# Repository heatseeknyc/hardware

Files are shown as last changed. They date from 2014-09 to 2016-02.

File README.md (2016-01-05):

## Heat Seek NYC Hardware

### Overview

connect XBee to the π via serial GPIO pins

listen for IO frames, which are of the form 0x7E....92

use a (manually maintained) mapping of 64-bit sensor addresses to apartments, to record apartment temperatures

### XBee-DigiMesh

Unlike XBee Zigbee, it supports synchronized sleeping, for low-power meshing.

The [chip](http://www.digikey.com/product-detail/en/XB24-DMPIT-250/602-1338-ND/3482610) — this is the same hardware as [XBee Series 1](http://www.digikey.com/product-detail/en/XB24-API-001/602-1273-ND/3482588) but with DigiMesh firmware pre-installed.

The [docs](http://ftp1.digi.com/support/documentation/90000991_L.pdf).

Adding a new node is slightly trickier, but if the π node is in "Synchronous Sleep Support Mode" SM=7, then you can just bring a new node near the π at any time and it will sync up with the rest of the sleeping (SM=8) nodes.

### Alternatives

#### XBee-Zigbee

Can't both sleep and mesh, but has a better ADC, perhaps among other things.

Make sure to connect VREF to VCC. This is basically undocumented, but without it the chip basically crashes after a minute of reading from the ADC. _TODO_ email Digi about this.

The [chip](http://www.digikey.com/product-detail/en/XB24-Z7PIT-004/602-1275-ND/3482624), aka XBee Series 2.

The [docs](http://ftp1.digi.com/support/documentation/90000976_S.pdf)

### GERBER Files
If you need to generate a GERBER file, follow the instructions in [this tutorial](https://learn.sparkfun.com/tutorials/using-eagle-board-layout/generating-gerbers). You just clone [their repo](https://github.com/sparkfun/SparkFun_Eagle_Settings) and use `sfe-gerb274x.cam`.

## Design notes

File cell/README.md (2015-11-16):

# Cell node

## Electrical

### Components

See the [spreadsheet](https://docs.google.com/spreadsheets/d/1aLX0yPriqRYv9exc7hV8ZaoWDZZKsPV997NUnLpyvPM/edit?usp=sharing).

#### Searching for capacitors
for now we're using Kemet X7R 50V ±10% ceramic 0805s and through-hole radial capacitors

so to search go [here](http://www.digikey.com/product-search/en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) and then filter by capacitance

#### Temperature Sensor Chips
- our current chip: [surface mount analog temperature sensor](http://www.digikey.com/product-detail/en/MCP9700AT-E%2FTT/MCP9700AT-E%2FTTCT-ND/3622388) ±2°C from 0°C to 70°C, $0.24
- [surface mount RTD](http://www.digikey.com/product-detail/en/PTS080501B500RP100/PTS0805500CT-ND/1666191) ±0.5°C from -40°C to 40°C, $1.91
- [surface mount analog temperature sensor](http://www.digikey.com/product-detail/en/DS600U%2B/DS600U%2B-ND/1197625), ±0.5°C from -20°C to 100°C, $2.58
- [ball grid array analog temperature sensor](http://www.digikey.com/product-detail/en/LMT70YFQT/296-42088-1-ND/5252841) ±0.2°C from -20°C to 90°C, $1.73

### Power consumption

The input range of the MCP1700 is about 3.5V to absolute maximum 6.5V,
so we use 4xAAA batteries, which gives us an initial voltage of about 6.4V, and a voltage of about 4V after 1000mAh.

- MCP1700 quiescent current < 4µA
- XBee cyclic sleep current < 50µA
- Xbee transmit current < 45mA / 250mA PRO
- XBee idle/receive current < 50mA / 55mA PRO
- XBee ADC current **??**
- MCP9700 operating current < 12µA

**TODO** measure these!
- total sleeping current < 54µA
- total waking current < 50mA / 250mA PRO

#### Setup mode

If we transmit constantly, we use 50mA / 250mA PRO, so every hour of setup we use 1.3% / 6.3% PRO of the batteries.

#### Live mode

So if we transmit for 5 seconds every hour, we use 124µAh / 402µAh PRO per hour, so 4x1000mAh battery would last 3.6 / 1.1 PRO years.

And if we transmit for 10 seconds every hour, we use 193µAh / 749µAh PRO per hour, so 4x1000mAh battery would last 2.3 / 0.6 PRO years.

## Mechanical

### flat battery holder mounting

assuming symmetry, mounting hole centers are offset from left and right edges by (1.98" - 0.5") / 2 = 0.74"

terminals are offset from bottom by 0.102"

### XBee dimensions, including *full height* of [socket](http://www.sullinscorp.com/drawings/75_1BFC_10483.pdf)

XBee is smaller than XBee-PRO, `32.94mm - 5.33mm = 27.61mm`

    24.38mm W x 27.61mm D x 9.79mm (2.79mm + 7.0mm) H

### battery holder dimensions

[3d model](flat-case-squat-case-and-us-quarter.stl) of flat and squat cases and a quarter

#### [flat](http://www.digikey.com/product-detail/en/2481/2481K-ND/303826)

    50.79mm W x 54.51mm D x 23.29mm (13.5mm + 9.79mm) H
    2.00" W x 2.15" D x 0.92" H

#### [squat](http://www.digikey.com/product-detail/en/BH24AAAW/BH24AAAW-ND/38633)

    26mm W x 53mm D x 35mm (25mm + 10mm) H

### cases

#### [TS-3315P](http://www.polycase.com/ts-3315p)

    3.00" x 3.00" x 1.50", weight=2.1oz, volume=13.5""", price=$2.05

#### [LP-41P](http://www.polycase.com/lp-41p)

    3.29" x 3.29" x 1.25", weight=3.2oz, volume=13.53""", price=$2.66

#### [CU-791](http://www.budind.com/view/Plastic+Boxes/Utilibox+Style+E)

    3.08" x 3.08" x 1.50", weight=1.5oz, volume=14.23""", price=$2.86

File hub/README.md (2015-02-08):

# Hub node

## Serial connection

- GPIO pin 1 (3v3) to XBee pin 1 (VCC)
- GPIO pin 6 (GND) to XBee pin 10 (GND)
- GPIO pin 8 (TXD) to XBee pin 3 (DIN)
- GPIO pin 10 (RXD) to XBee pin 2 (DOUT)

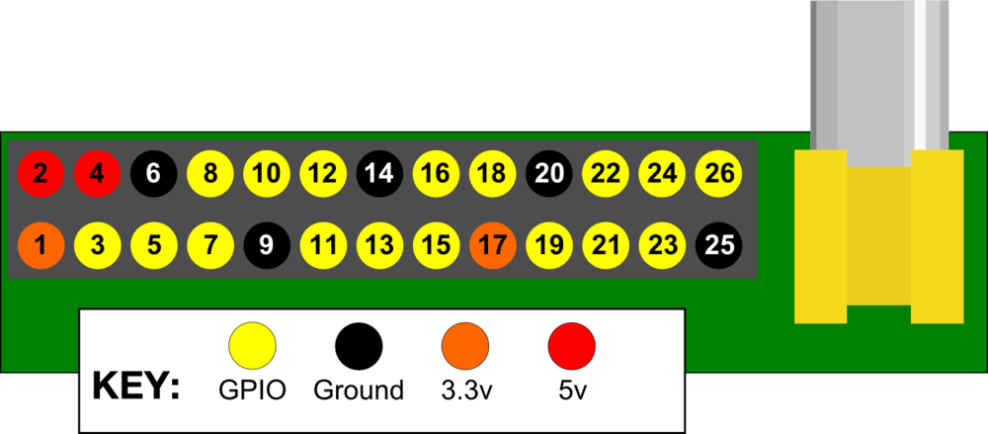
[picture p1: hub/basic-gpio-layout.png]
GPIO pin layout


## Data usage

Assuming each reading is ~100 bytes (the reading itself may be as little as 20-30 bytes, plus the HTTP headers), and each cell takes 24 readings per day, that's 24 x 100 = 2,400 bytes per day per cell, or 2.4 kilobytes (roughly, 1kb = 1024b).

Assuming a base is connected to 10 cells, then the base will be transmitting 10 x 2.4 = 24 kilobytes per day.
Assuming 31 days per month (worst case), and 365 days per year, data usage will be:

|numCells|Data/Day|Data/Month|Data/120d|Data/Year|
|---|---|---|---|---|
|1 |2.4 kb  |0.0744 mb |0.288 mb |0.876 mb |
|10 |24 kb |0.744 mb  |2.88 mb  |8.76 mb  |
|15 |36 kb |1.17 mb |4.32 mb  |13.14 mb |
|20 |48 kb |1.48 mb |5.76 mb  |17.52 mb |
|30 |72 kb |2.23 mb |8.64 mb  |26.28 mb |
|50 |120 kb  |3.72 mb |14.4 mb  |43.8 mb  |
|100 |240 kb  |7.44 mb |28.8 mb  |87.6 mb  |

Pre-paid Vodafone SIM cards:
- [1MB/month for a year](http://www.embeddedworks.net/wsim2730.html) for $31.27, or $2.61/MB
- [5MB/month for 6 months](http://www.embeddedworks.net/wsim2737.html) for $46.11, or $1.54/MB
- [10MB/month for a year](http://www.embeddedworks.net/wsim2786.html) for $137.41, or $1.15/MB

## 3G modems

There's a [generic stick](http://www.amazon.com/Generic-Wireless-7-2Mbps-Dongle-Function/dp/B00MHAKIJY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) for ~$13 and a [branded alternative](http://www.amazon.com/Huawei-E173-Unlocked-HSDPA-7-2Mbps/dp/B0055310KQ) for ~$26. Given that we currently budget $6 for a USB WiFi dongle, each of these represents some increase to the cost of the base, $7 and $20, respectively.

[Verified 3G USB dongles](http://elinux.org/RPi_VerifiedPeripherals#USB_3G_Dongles)

## Alternatives

connect the HSDPA (3G) dongle to an [Arduino USB Host Shield](https://www.sparkfun.com/products/9947), to see how easy direct USB 3G modem AT commands are... possibly not easy.

connect a [FONA GSM (2G) board](https://www.adafruit.com/fona) to an Arduino or whatever. this isn't cheaper than a Raspberry Pi, but could lead to a cheaper PCB.

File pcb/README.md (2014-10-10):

#### XBee dimensions, including [socket](http://www.sullinscorp.com/drawings/75_1BFC_10483.pdf)

25mm W x 28mm L x 10mm (3mm + 7mm) D

#### battery holder dimensions

https://github.com/heatseeknyc/hardware/blob/master/pcb/flat-case-squat-case-and-us-quarter.stl

##### [flat](http://www.digikey.com/product-detail/en/2481/2481K-ND/303826)

51mm W x 54mm L x 23mm (13mm + 10mm) D (assuming PC pins are clipped)

##### [squat](http://www.digikey.com/product-detail/en/BH24AAAW/BH24AAAW-ND/38633)

26mm W x 53mm L x 35mm (25mm + 10mm) D

#### flat battery holder mounting

assuming symmetry, mounting hole centers are offset from left and right edges by (1.98" - 0.5") / 2 = 0.74"

terminals are offset from bottom by 0.102"

#### searching for capacitors

for now we're using Kemet X7R 50V ±10% ceramic 0805s and through-hole radial capacitors

so to search go [here](http://www.digikey.com/product-search/en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) and then filter by capacitance

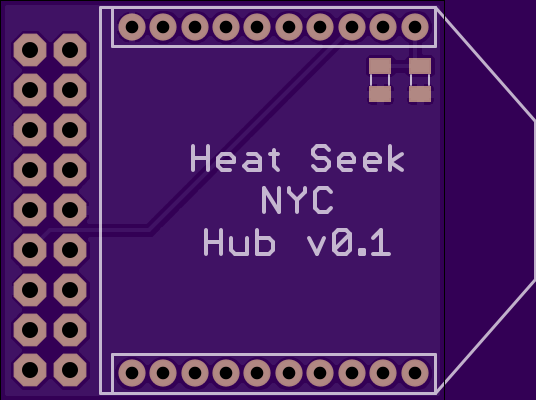
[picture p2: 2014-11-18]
hub/without/v0.1.png

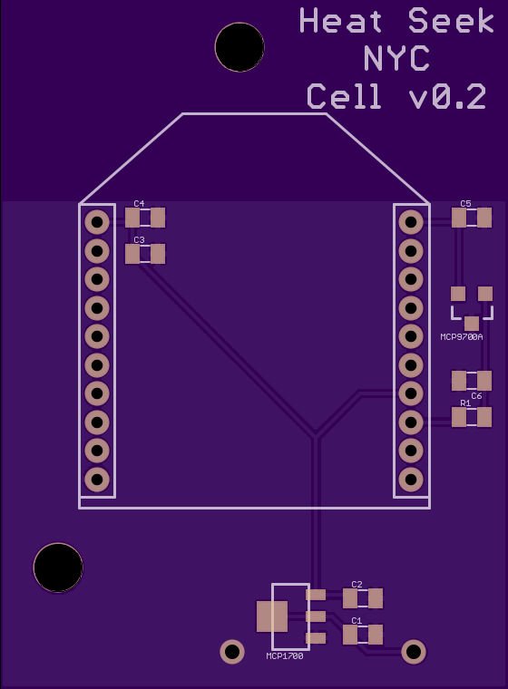
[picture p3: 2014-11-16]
cell/v0.2.png

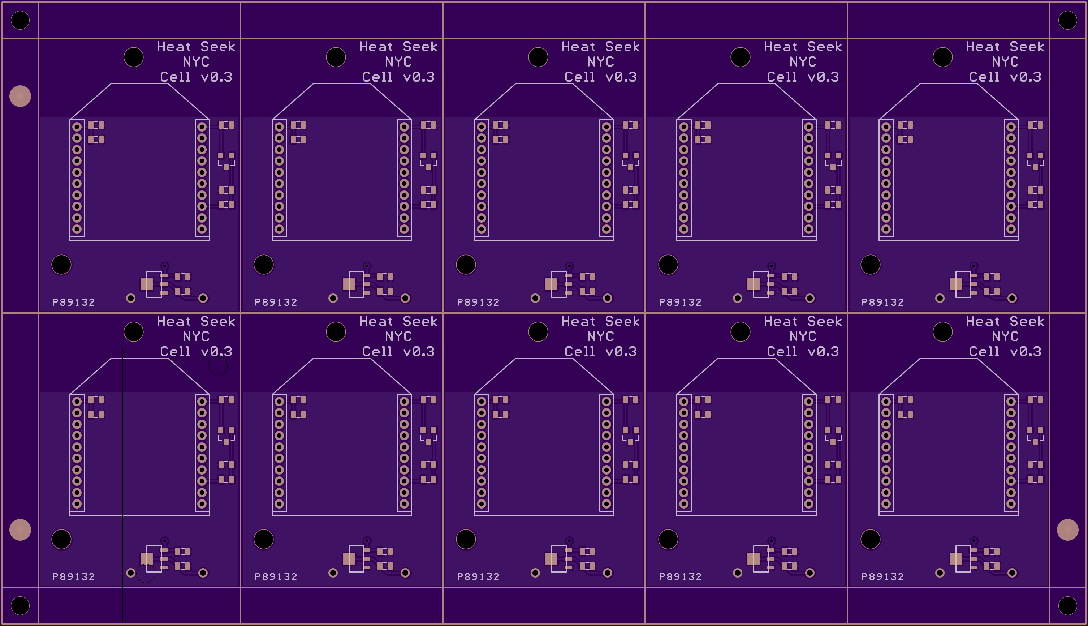
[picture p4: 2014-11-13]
cell/v0.3-array.png

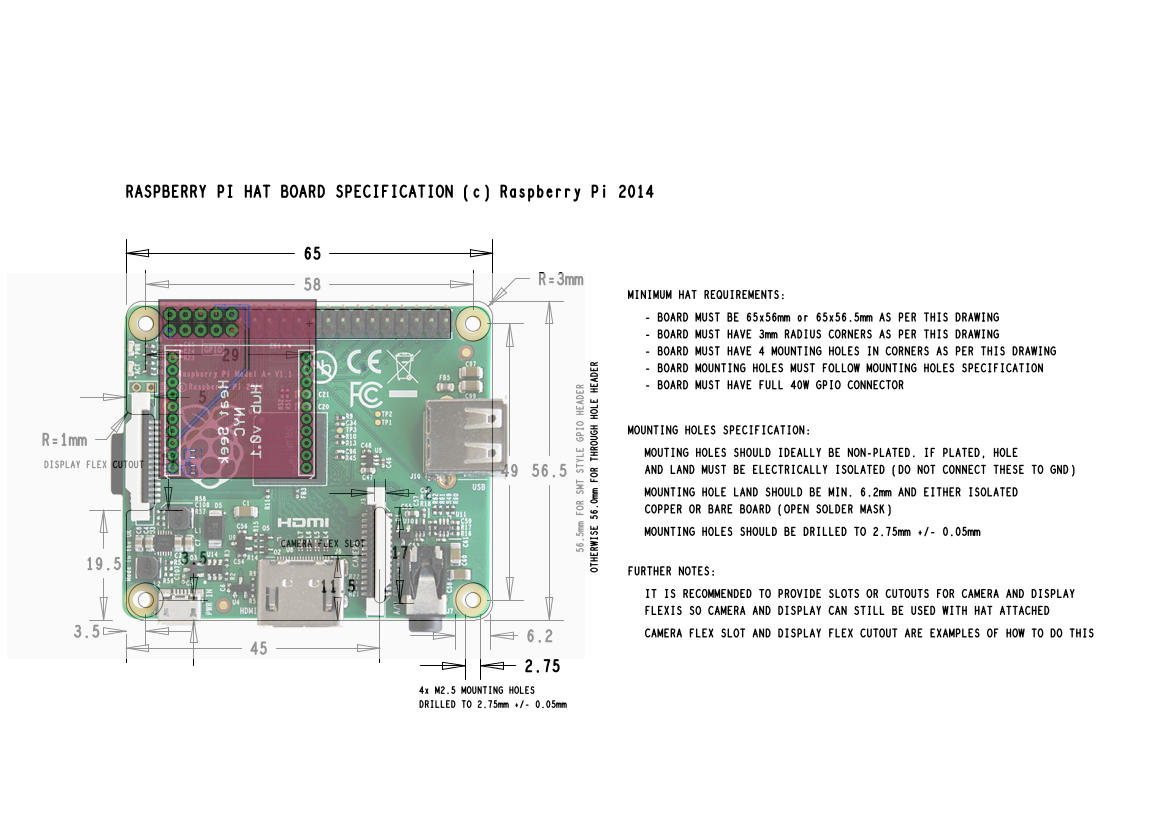
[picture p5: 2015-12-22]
hub/stacked/v0.1-within.png

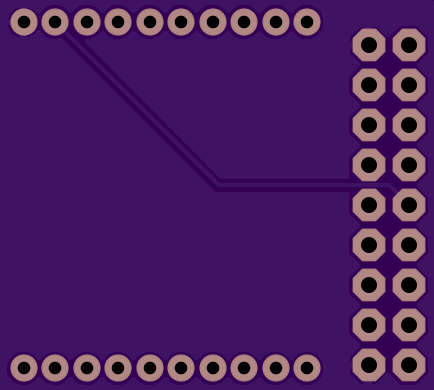
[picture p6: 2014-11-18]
hub/v0.1-bottom.png

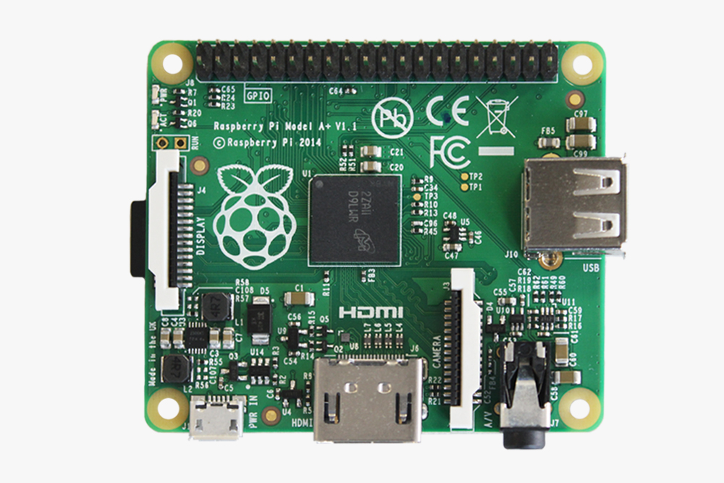
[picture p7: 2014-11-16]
hub/stacked/π-a+.jpg

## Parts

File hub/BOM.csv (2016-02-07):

Description | QTY | Ref Des | Mfg P/N # | Distributor | Distributor P/N #
CAP CER 1UF 50V 10% X7R 0805 | 1 | C1 | C0805C105K5RACTU | Digi-Key | 399-7409-1-ND
CAP CER 8.2PF 50V NP0 0805 | 1 | C2 | C0805C829D5GACTU | Digi-Key | 399-8121-1-ND
CONN FMALE 18POS DL .1" GOLD SMD | 1 | Rπ | NPPC092KFMS-RC | Digi-Key | S5718-ND
CONN RECEPT 2MM SINGLE STR 10POS | 2 | XB1, XB2 | NPPN101BFLC-RC | Digi-Key | S5901-10-ND

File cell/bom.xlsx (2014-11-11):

Description | QTY | Ref Des | Mfg P/N # | Distributor | Distributor P/N #
HOLDER BATTERY 4CELL AAA PC MNT (http://www.digikey.com/product-detail/en/2481/2481K-ND/303826) | 1 |  | 2481 | Digi-Key | 2481K-ND
CONN RECEPT 2MM SINGLE STR 10POS (http://www.digikey.com/product-detail/en/NPPN101BFCN-RC/S5751-10-ND/804812) | 2 |  | NPPN101BFCN-RC | Digi-Key | S5751-10-ND
IC REG LDO 3.3V 0.25A SOT89-3 (http://www.digikey.com/product-detail/en/MCP1700T-3302E%252FMB/MCP1700T3302EMBCT-ND/652679) | 1 | MCP1700 | MCP1700T-3302E/MB | Digi-Key | MCP1700T3302EMBCT-ND
IC SENSOR THERMAL 2.3V SOT-23-3 (http://www.digikey.com/product-detail/en/MCP9700AT-E%252FTT/MCP9700AT-E%252FTTCT-ND/3622388) | 1 | MCP9700A | MCP9700AT-E/TT | Digi-Key | MCP9700AT-E/TTCT-ND
CAP CER 1UF 50V 10% X7R 0805 (http://www.digikey.com/product-detail/en/C0805C105K5RACTU/399-7409-1-ND/3317443) | 4 | C1, C2, C3, C6 | C0805C105K5RACTU | Digi-Key | 399-7409-1-ND
CAP CER 8.2PF 50V NP0 0805 (http://www.digikey.com/product-detail/en/C0805C829D5GACTU/399-8121-1-ND/3471844) | 1 | C4 | C0805C829D5GACTU | Digi-Key | 399-8121-1-ND
CAP CER 0.1UF 50V 10% X7R 0805 (http://www.digikey.com/product-detail/en/C0805C104K5RACTU/399-1170-1-ND/411445) | 1 | C5 | C0805C104K5RACTU | Digi-Key | 399-1170-1-ND
RES 200 OHM 1/8W 1% 0805 (http://www.digikey.com/product-detail/en/RC2012F201CS/1276-5234-1-ND/3968206) | 1 | R1 | RC2012F201CS | Digi-Key | 1276-5234-1-ND

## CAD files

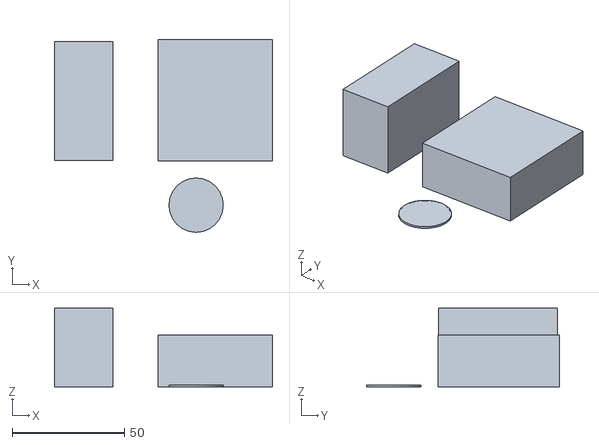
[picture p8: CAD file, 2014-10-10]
cell/flat-case-squat-case-and-us-quarter.stl
97.1 x 85.9 x 35.0

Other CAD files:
cell/cases.skp

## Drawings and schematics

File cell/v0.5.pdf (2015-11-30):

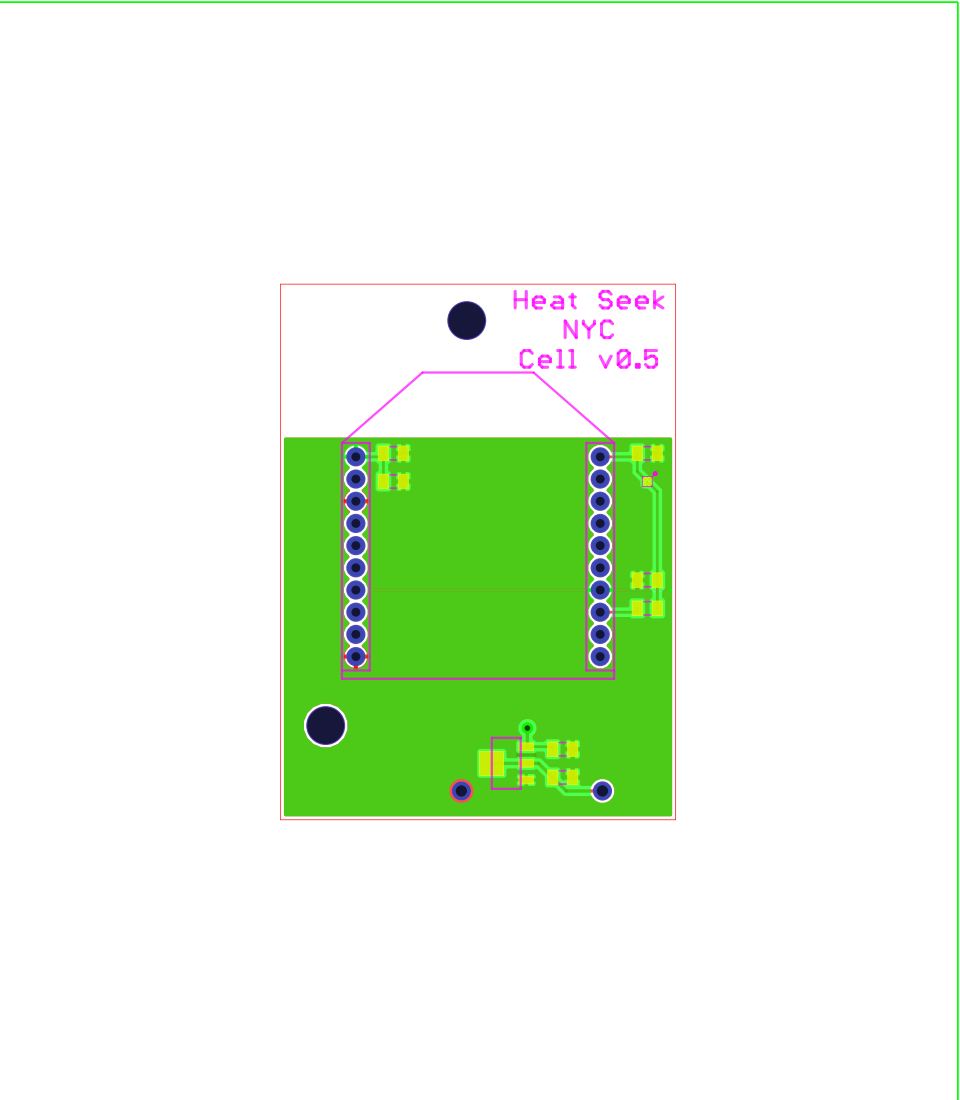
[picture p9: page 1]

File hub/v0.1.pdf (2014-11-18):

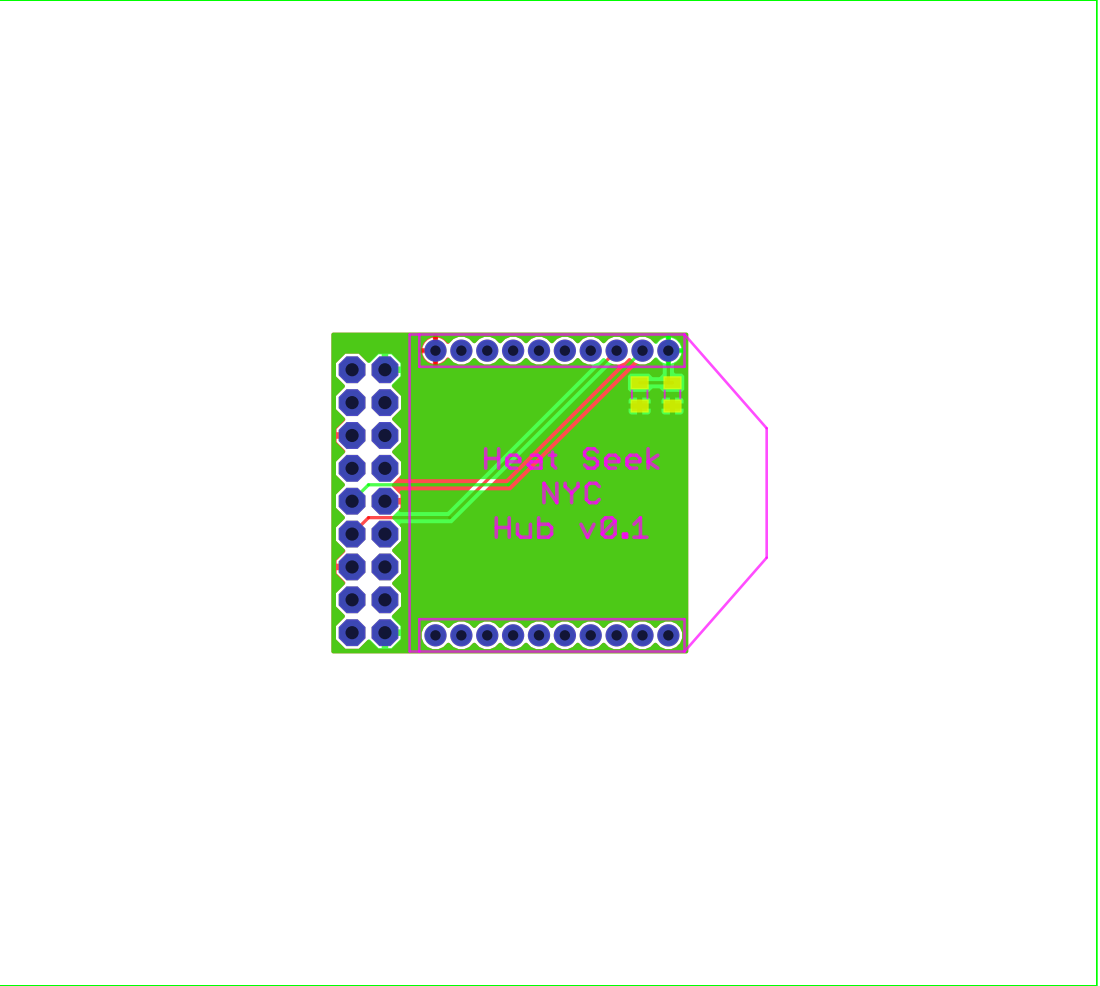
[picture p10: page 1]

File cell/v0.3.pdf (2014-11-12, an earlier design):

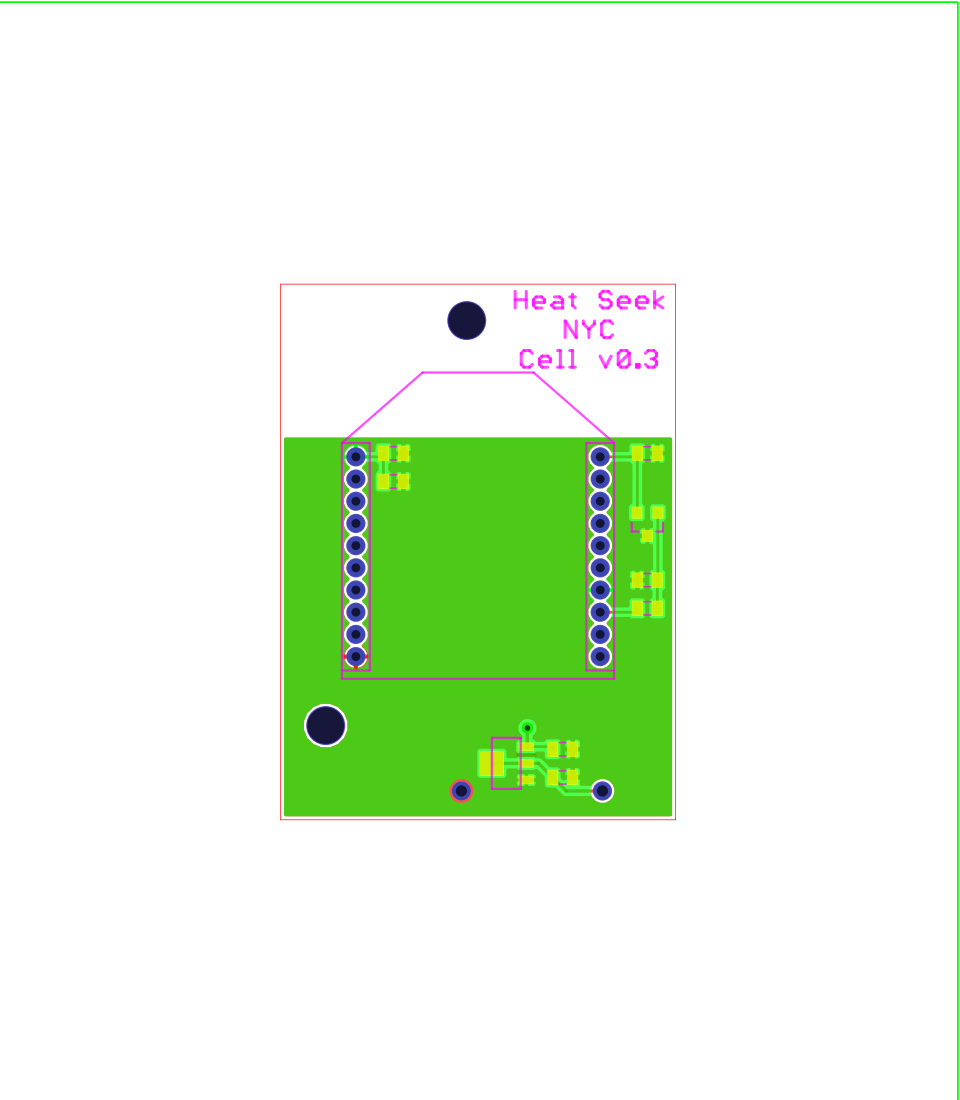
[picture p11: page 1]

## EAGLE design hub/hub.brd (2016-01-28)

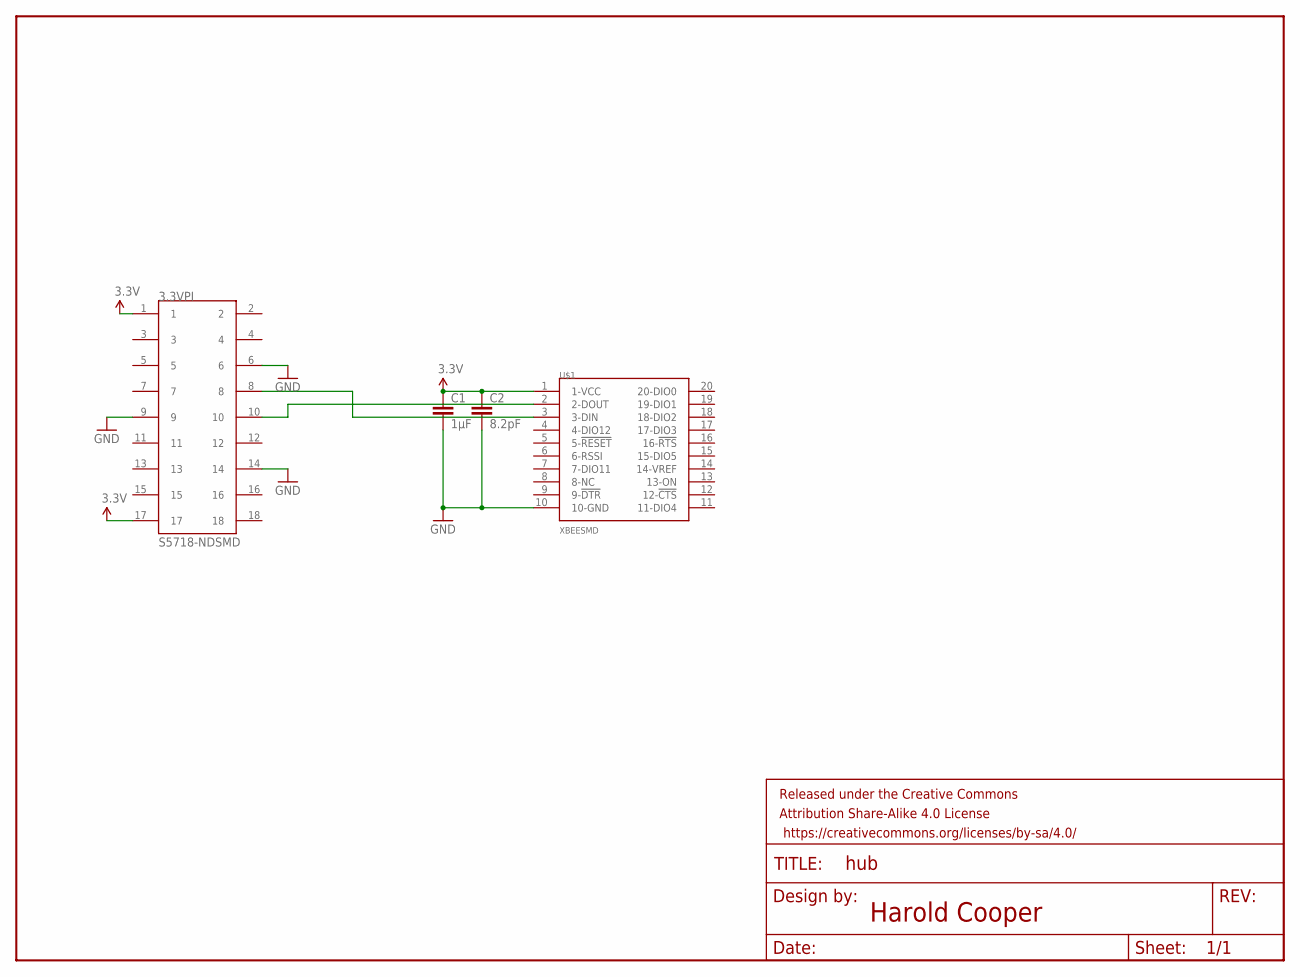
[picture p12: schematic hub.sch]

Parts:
3.3VPI: S5718-NDSMD; CONN_HEADER_SMD_18
C1: 1µF; 0805
C2: 8.2pF; 0805
FRAME1: FRAME-LETTER; CREATIVE_COMMONS
U$1: XBEESMD; CONN_HEADER_SMD_10X2

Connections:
3.3V: 3.3VPI.1, 3.3VPI.17, C1.1, C2.1, U$1.1 (1-VCC)
GND: 3.3VPI.6, 3.3VPI.9, 3.3VPI.14, C1.2, C2.2, U$1.10 (10-GND)
unnamed: 3.3VPI.10, U$1.2 (2-DOUT)
unnamed: 3.3VPI.8, U$1.3 (3-DIN)

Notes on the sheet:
Harold Cooper

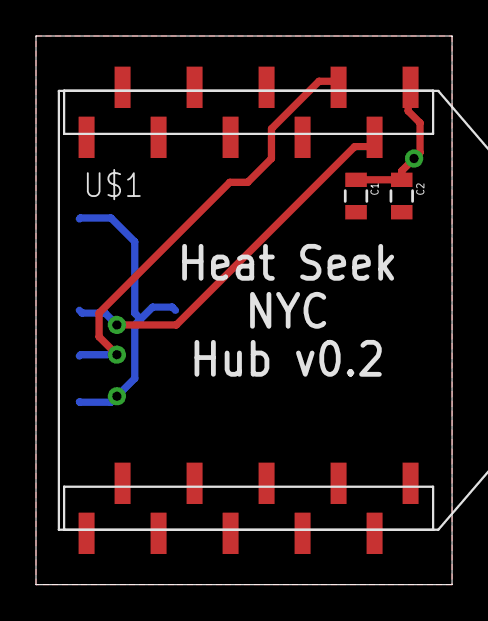
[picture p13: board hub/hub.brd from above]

Board: 2 copper layers, 23.1 x 30.5 mm, 5 parts (0 on the bottom side), 4 nets.

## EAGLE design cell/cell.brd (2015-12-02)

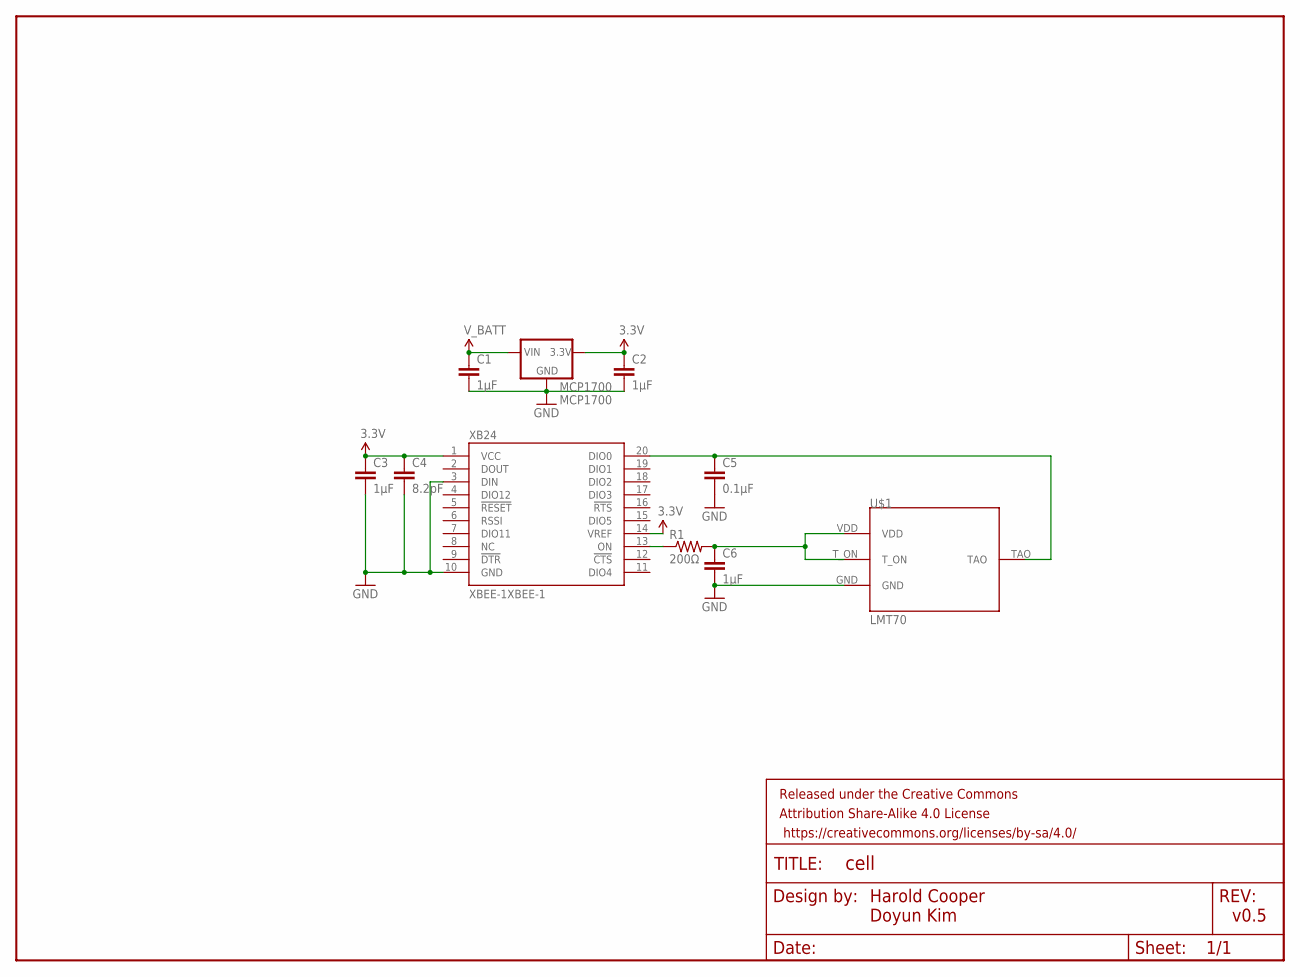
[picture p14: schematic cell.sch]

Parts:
C1, C2, C3, C6: 1µF; 0805
C4: 8.2pF; 0805
C5: 0.1µF; 0805
FRAME1: FRAME-LETTER; CREATIVE_COMMONS
MCP1700: MCP1700; SOT-89-3
R1: 200Ω; 0805
U$1: LMT70; YFP0004
XB24: XBEE-1XBEE-1; XBEE-1

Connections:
3.3V: C2.1, C3.1, C4.1, MCP1700.3 (3.3V), XB24.1 (VCC), XB24.14 (VREF)
GND: C1.2, C2.2, C3.2, C4.2, C5.2, C6.2, MCP1700.1 (GND), U$1.GND, XB24.3 (DIN), XB24.10 (GND)
unnamed: C6.1, R1.2, U$1.T_ON, U$1.VDD
unnamed: R1.1, XB24.13 (ON)
unnamed: C5.1, U$1.TAO, XB24.20 (DIO0)
V_BATT: C1.1, MCP1700.2 (IN)

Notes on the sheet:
Harold Cooper Doyun Kim
v0.5

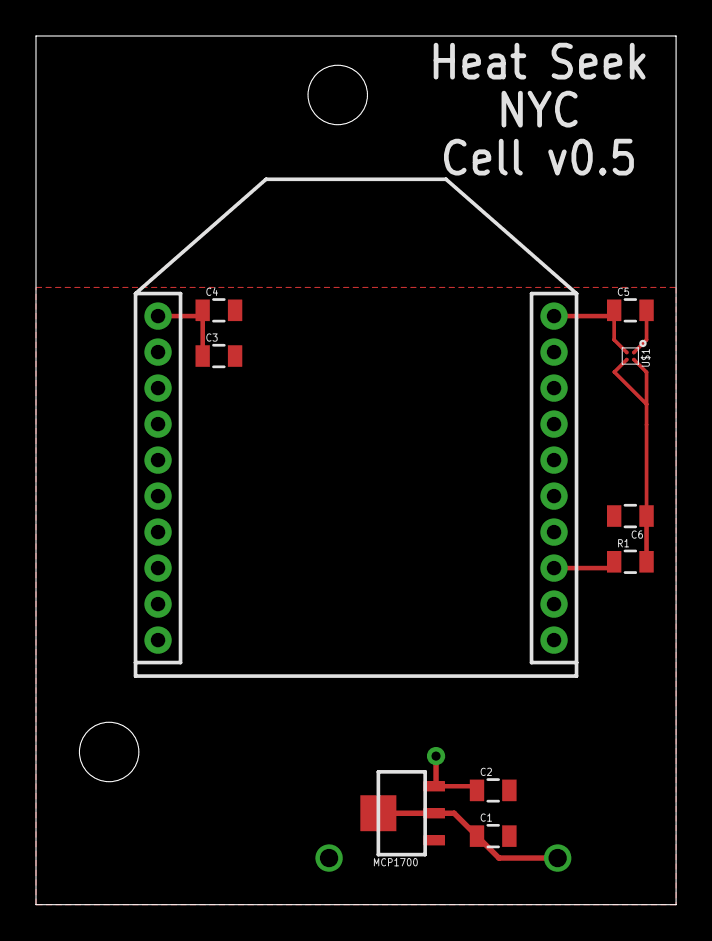
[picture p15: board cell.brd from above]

Board: 2 copper layers, 35.6 x 48.3 mm, 11 parts (0 on the bottom side), 6 nets.

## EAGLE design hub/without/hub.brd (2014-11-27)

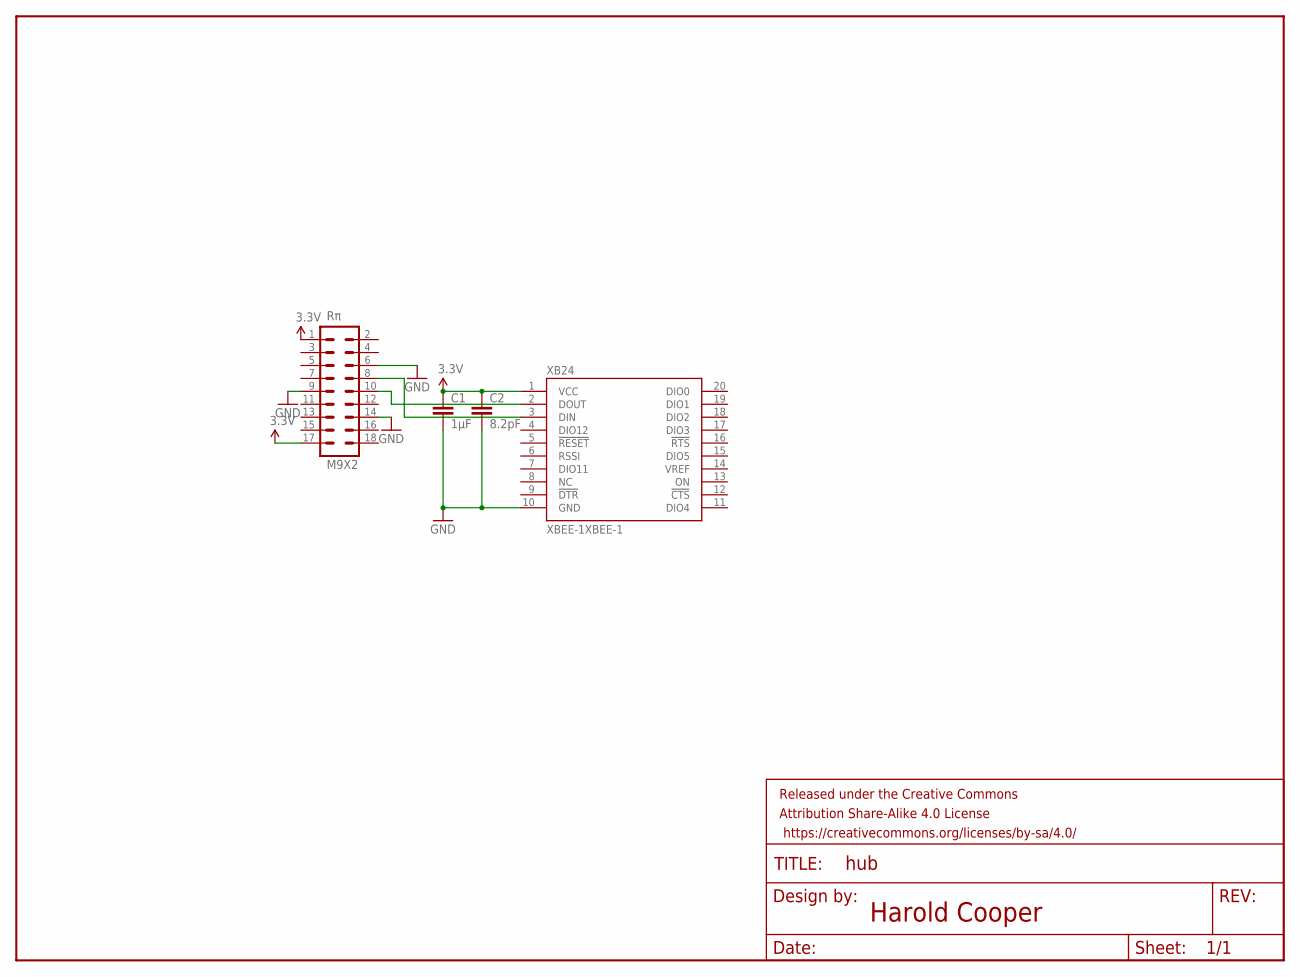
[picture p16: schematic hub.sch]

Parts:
C1: 1µF; 0805
C2: 8.2pF; 0805
FRAME1: FRAME-LETTER; CREATIVE_COMMONS
Rπ: M9X2; 2X9_NOSILK
XB24: XBEE-1XBEE-1; XBEE-1

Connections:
3.3V: C1.1, C2.1, Rπ.1, Rπ.17, XB24.1 (VCC)
GND: C1.2, C2.2, Rπ.6, Rπ.9, Rπ.14, XB24.10 (GND)
unnamed: Rπ.10, XB24.2 (DOUT)
unnamed: Rπ.8, XB24.3 (DIN)
VREF: XB24.14 (VREF)

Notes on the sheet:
Harold Cooper

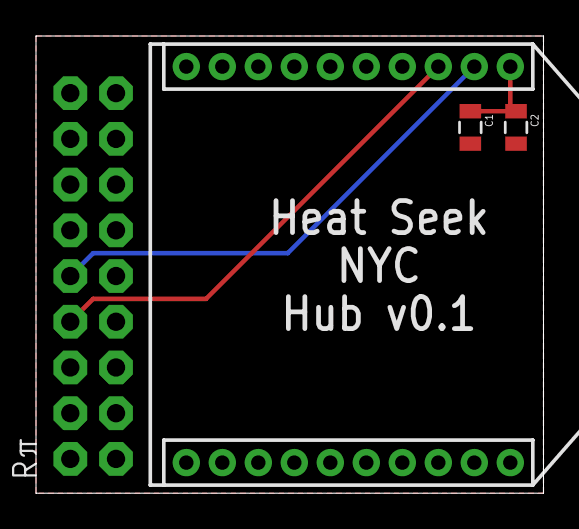
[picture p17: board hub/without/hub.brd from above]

Board: 2 copper layers, 28.2 x 25.4 mm, 5 parts (0 on the bottom side), 4 nets.

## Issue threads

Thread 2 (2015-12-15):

new cell v0.5 is reporting the wrong temperature

williamcodes, 2015-12-15:
The first v0.5 cell tested ([C509](http://relay.heatseeknyc.com/cells/0013a20040dc273e)) is reporting 111ºF in live mode from inside our improvised thermal chamber along with an extech air probe reporting 73ºF.

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

hrldcpr, 2015-12-15:
This is (hopefully) not a hardware issue, but something we should change in firmware and perhaps relay.

In particular, the formula here - https://github.com/heatseeknyc/firmware/blob/2dadd864efc0256e5e55427ce842b3f6e683f441/hub/receiver.py#L57 - only applies to the old temperature chip, so we need a place (probably the relay server) that knows which type of board is being used and then uses the correct formula.

thus, two new issues:
heatseeknyc/firmware#9
heatseeknyc/relay#11

Closed 2015-12-15.

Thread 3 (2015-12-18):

add GERBER files or procedure for making them

williamcodes, 2015-12-18:
Manufacturers keep asking for them, maybe we should have them under version control. My only concern is that it could end up out of sync with the eagle file, which I think should be the source of truth. If that's the case, perhaps it'd be easier to put instructions in the README for how to make them. I'd love an automated build process that generates it, but that sounds like way more work than it's worth.

williamcodes, 2015-12-18:
I can take a crack at this one.

hrldcpr, 2015-12-19:
[This tutorial](https://learn.sparkfun.com/tutorials/using-eagle-board-layout/generating-gerbers) is good. You just clone [their repo](https://github.com/sparkfun/SparkFun_Eagle_Settings) and use `sfe-gerb274x.cam`

I usually avoid committing generated content, but meh whatever.

Closed 2016-01-05.

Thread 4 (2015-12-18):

update the hub board design to eliminate through-hole components

williamcodes, 2015-12-18:
They're easy to solder in prototyping, but expensive to manufacture. Also, we have a manufacturing partner that wants to work with us with INSANE discounts but can't do through-hole components. If we can switch to SMD headers, then we can work with them. They said that thought it would probably only take an hour to update the eagle file.

williamcodes, 2015-12-22:
### Copied from Doyun's email

I have questions on this issue.
So what I need to do is make two parts (xbee and raspberry pi gpio header part) surface mounted form.

1. It seems like xbee part is made by Harold. I thought it's through-hole but the picture William sent to me has a header. They look different to me , so I want to know what component it is.
2. We have two versions on Github, within and without. What's the difference and should I update both?
3. I guess this hub part will be a hat to raspberry pi. This header is using M9X2 device and 2X9_NOSILK package from Harold's library. Is this also through-hole or similar to what I saw in above picture?
4. I want to see the picture of previous hub!

williamcodes, 2015-12-22:
1. I'm not sure I follow actually. What is the question?
2. Excellent question! I have no idea. @hrldcpr what's the difference between within and without? Looks like something to do with space saving? Confused.
3. Yes, I love that, the hub part is the raspberry pi's hat. He's got great fashion sense! As for the pin headers, they are currently through-hole components. @hrldcpr can you confirm that? Perhaps the photo will clear things up.
4. Photo shoot! Time to show of that swanky hat.
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

hrldcpr, 2015-12-23:
1. Yeah the "XBee" part was really just a way to align things, in reality it is two headers, specifically this one - http://www.digikey.com/product-detail/en/NPPN101BFCN-RC/S5751-10-ND/804812
2. `within` was an alternative design that we never used. I've gone ahead and deleted it from the repo to make things clearer.
3. All three headers in the current design are through-hole. The header that connects to the π is this one - http://www.digikey.com/product-detail/en/PPPC092LFBN-RC/S7112-ND/810249

qelloman, 2015-12-23:
**Raspberry pi header replacement** :
small amount (minimum quantity 1) : http://www.digikey.com/product-detail/en/NPPC092KFMS-RC/S5718-ND/776177
large amount (minimum quantity 1000) : http://www.digikey.com/product-detail/en/NPTC092KFMS-RC/S5679-ND/776138

**XBee header replacement** : http://www.digikey.com/product-detail/en/NPPN101BFLC-RC/S5901-10-ND/810012

Prices are more expensive than those of through-hole version.
I think board size also needs to be increased.

qelloman, 2015-12-30:
@hrldcpr Why did you use two different capacitor for VCC?
one is 1uF and another is 8.2pF. They are close so it seems like 8.2pF cap is in use.

hrldcpr, 2015-12-30:
@qelloman good question, I wondered about that too since it seems like it would be equivalent to a 1.0082µF capacitor, which makes the 8.2pF seem pointless… but it's from the [XBee documentation](http://ftp1.digi.com/support/documentation/90000991.pdf), page 22:
> To help reduce noise, place a 1.0 μF and 8.2 pF capacitor as near as possible to pin 1 on the PCB.

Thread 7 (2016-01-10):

calibrate v0.5 cells at multiple temperatures

hrldcpr, 2016-01-10:
We should write down times and temperature readings from the HPD-approved thermometers that correspond to specific times and readings from a few v0.5 cells, at a few different temperatures.

This will allow us to construct a voltage-vs-temperature curve for the v0.5 cells, and to see how consistent readings are between different cells.

(It would be nice to have a few v0.3 cells also involved, because more data is merrier, but that's less crucial.)

williamcodes, 2016-01-11:
I'm doing my testing in the office now. It's going to take several hours since it reads hourly but I'll periodically update this comment.

http://relay.heatseeknyc.com/hubs/0013a20040bf9f8d

Taken At | Cell ID | Temperature | Sleep Period | Received At  | Version | Extech
------------ | --------- | ----------------- | ----------------- | -----------------  | ---------- | ---------
2016-01-11 16:25:20+00:00 | 0013a20040c17e69	| 74.39° | 359000 | 2016-01-11 16:25:36.930578+00:00 | v0.3 | 74.3º

williamcodes, 2016-01-12:
I wasn't able to simulate extreme temperatures very well. Without a proper thermal chamber, the best I could do was introduce a heating / cooling element into the box. I used an ice pack and hot water. This introduces a lot of variability within the same zone. @qelloman offered to let us use the thermal chamber at Columbia, hopefully that will improve this data.

hrldcpr, 2016-01-12:
Cool thanks! I'll see if I can use this to better calibrate the v0.5 cells when I'm back in NYC at the end of the week.

If you want to do more testing without going up to Columbia, you could just put a cell outside, that would be extreme enough.

williamcodes, 2016-01-27:
Man, I can't believe I let this go 15 days, my apologies, we've been totally slammed. Anyway, Noelle was able to get some good readings both on her fire escape and on her desk above her radiator. Here are the numbers:

short code | time | version | temperature
---------------|-------|-----------|------------------
[786a](http://relay.heatseeknyc.com/cells/786a) | 8:30pm | v0.3 | 44.77
[c509](http://relay.heatseeknyc.com/cells/c509) | 8:30pm | v0.5 | 127.23
Extech 39240 | 8:30pm | v0.3 | 44.2
| | |
| | |
[786a](http://relay.heatseeknyc.com/cells/786a) | 9:30pm | v0.3 | 44.19
[c509](http://relay.heatseeknyc.com/cells/c509) | 9:30pm | v0.5 | 127.81
Extech 39240 | 9:30pm | v0.3 | 44.19
| | |
| | |
[786a](http://relay.heatseeknyc.com/cells/786a) | 11:30pm | v0.3 | 88.9
[c509](http://relay.heatseeknyc.com/cells/c509) | 11:30pm | v0.5 | 102.26
Extech 39240 | 9:30pm | v0.3 | 88.1

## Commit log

2014-06-17 note about weird ADC
2014-06-17 DIO0 defaults to "commissioning button" so we'll leave it alone and use the disabled AD1
2014-07-12 script for parsing xbee sensor readings from serial
2014-07-18 since we are reading from a file that is actively being written, we'll avoid the last line in case it's incomplete
2014-07-18 delimit with tabs for readability
    [readings.tsv]
2014-07-18 round times and temperatures, don't truncate
2014-07-18 moved data into data/ directory, which is gitignored. renamed 'sofar.txt' to 'progress'
    [readings.tsv]
2014-08-08 digimesh battery life caclulations
2014-09-04 print extra info after unsuccessful heatseek POSTs
2014-09-10 new plan for π serial
2014-09-12 3g usb π link
2014-09-14 serial pin connections
2014-09-17 log adc details
2014-09-30 updated power consumption assuming 3xAAA
2014-10-01 initial cell schematic
2014-10-02 eagle files
    [cell.brd, cell.sch]
2014-10-02 whoops we need to leave schematic.pdf there since we just linked to it on kickstarter :hear_no_evil:
2014-10-08 remove ±10% constraint, since smaller capacitors aren't listed that way
2014-10-08 remove X7R constraint, since smaller capacitors aren't listed that way
2014-10-10 add pcb text
    [cell.brd, cell.sch]
2014-10-10 cell v0.1, as ordered from OSH Park on 2014-10-07
    [cell.brd, cell.sch]
2014-10-10 pcb folder
    [cell.brd, cell.sch]
2014-10-10 dimensions for both flat and "squat" battery holders
2014-10-10 STL model of cases
    [cases.stl]
2014-10-10 sketchup model
    [cases.skp]
2014-10-13 cell, hub, and π folders
    [cases.skp, cell.brd, cell.sch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]
2014-11-03 π notes
2014-11-10 cell v0.2, with on-board temperature sensor and better layout
    [cell.brd, cell.sch]
2014-11-11 cell v0.3, with power plane eliminating the major traces
    [cell.brd]
2014-11-11 board images
2014-11-11 BOM and CPL spreadsheets
    [bom.xlsx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]
2014-11-11 increase width and isolation of pours, as per https://www.sparkfun.com/tutorials/115
    [cell.brd]
2014-11-11 increase supply traces from 10mil to 12mil
    [cell.brd]
2014-11-11 don't show names, turns out assembly shouldn't need them
    [cell.brd]
2014-11-13 5x2 cell array that Advanced Circuits is printing
2014-11-13 hub pcb v0.1
    [hub.brd, hub.sch]
2014-11-13 gitignore gerbers
2014-11-16 closest you can get to Bailey's without getting your nose wet
    [hub.brd]
2014-11-16 use the largest header we can fit, for stability and to look cool?
    [hub.brd, hub.sch]
2014-11-16 within/ for board that tries to fit inside case
    [hub.brd, hub.sch]
2014-11-16 without/ for board outside of case, for Pimoroni A+ case
    [hub.brd, hub.sch]
2014-11-16 tighter fit, turns out XBee fits perfectly on 1" wide board
    [hub.brd]
2014-11-18 outside-of-case hub board previews
2014-11-27 rename chips
    [hub.brd, hub.sch]
2015-01-05 DIN/!CONFIG pull-up resistor must not be disabled!
    see the WARNING here - http://www.digi.com/support/kbase/kbaseresultdetl?id=3522
    :sob:
2015-01-05 ground DIN/!CONFIG so that we can safely disable its pullup resistor
    [cell.brd, cell.sch]
2015-01-05 reference new PR settings for new v0.4 cell board
2015-01-14 π keyboard layout defaults to UK
2015-01-22 π is hard to type on linux :sob:
2015-01-27 distinguish 'readings', which contain 'temperatures'. transmit raspberry pi serial number as hub id. store python dependencies in requirements.txt
2015-02-04 use network id of 311 (the number NYC residents call to report heating violations!); less likely to have conflicts with the default network id
2015-02-07 moved pi to heatseeknyc/pi
2015-02-08 moved firmware settings to heatseeknyc/pi
2015-02-22 updated power estimates, including XBee PRO
2015-02-24 pull-up resistors don't pull from ground, duh :sob:
2015-11-16 list current and alternative temperature sensors
2015-11-27 replace MCP9700A with LMT70
    [cell.brd, cell.sch]
2015-11-27 continues using sparkfun's eagle settings - https://github.com/sparkfun/SparkFun_Eagle_Settings/blob/master/scr/eagle.scr
    [cell.brd]
2015-11-27 center LMT70 with other chips
    [cell.brd]
2015-11-27 fix LMT70 naming
    [cell.brd, cell.sch]
2015-12-01 use symmetric traces on BGA chip, to avoid unequal soldering and tension
    [cell.brd]
2015-12-02 use smallest traces allowed by TI's AN-1112 doc (205µm) and smallest soldermask swell allowed by Advanced Circuits (5mil) to maximize the amount of mask separating the pads. this gives a 332µm solder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
    [cell.brd, cell.sch]
2015-12-22 get rid of 'within' hub board design, since we don't use it
    [hub.brd, hub.sch]
2016-01-05 Add GERBER instructions to README, closes #3
2016-01-27 drc error fixed and gerber files are created
    [hub.GBL, hub.GBO, hub.GBS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]
2016-01-28 fix DRC angle errors by removing tiny traces
    [hub.brd]
2016-01-28 don't track generated content
    [hub.GBL, hub.GBO, hub.GBS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]
2016-02-06 Add updated BOM file for SMT components
    [BOM.csv]

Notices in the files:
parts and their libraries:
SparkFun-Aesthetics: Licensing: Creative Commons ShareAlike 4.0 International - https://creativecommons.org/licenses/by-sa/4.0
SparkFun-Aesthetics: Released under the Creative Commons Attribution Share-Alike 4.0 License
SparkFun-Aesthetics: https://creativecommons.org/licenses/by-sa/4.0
